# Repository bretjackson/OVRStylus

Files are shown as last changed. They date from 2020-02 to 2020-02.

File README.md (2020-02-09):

# OVR Stylus

Picture of a user holding the OVR Stylus

The OVR Stylus is an open-source software/hardware design for a 3D input stylus used in virtual and augmented reality applications. With a touch pad, two input buttons, LRA-based vibrotactile haptic feedback, and Bluetooth communication, the 3D-printed prop’s light-weight design (35g) enables creative and precise interaction.

A paper describing the implementation was published at the [Workshop on Novel Input Devices and Interaction Techniques](https://sites.google.com/view/nidit) at the IEEE Virtual Reality 2020 conference. 

This repository archives the files needed to create your own OVR Stylus or to create a modified design.

## Repository Contents

* **/Case** - 3D printing files for the stylus case (.stl, Fusion 360 .f3z)
* **/Documentation** - A copy of the NIDIT paper (.pdf)
* **/Firmware** - Arduino  code used in the stylus and central device
* **/Hardware** - Eagle design files, BOM, Gerber files (.brd, .sch, etc.)
* **/VRPN** - Patch file and stylus classes to integrate with the [VRPN library](https://github.com/vrpn/vrpn)

### Hardware Manufacture

Stylus Components

#### PCB

The hardware directory contains the design files needed to print the custom circuit board. The gerber files can be uploaded directly to manufactures (e.g. [Seeed Fusion Studio](https://www.seeedstudio.com/fusion.html)). Ordering specifications including board thickness and other properties are listed in the `PCB Specs - Ordering Info` file. The component placement list and assembly drawing can be used for pick-n-place machines if using professional assembly.

To modify the design the Autodesk Eagle design files for the schematic and board layout are also included.

#### Haptic Controller

The design uses the Fyber Labs [LRA Haptic Flex Module](https://www.tindie.com/products/fyberlabs/lra-haptic-flex-module/). A Samsung 8mm LRA motor can be purchased from the same website. Solder the motor leads to the +0 and -0 through-hole pads. Connect the PWM pad to the stylus's P3 pad. The VIN, GND, SDA, and SCL pads can be connected to the respective pads on the stylus. I recommend using 28 gauge stranded wire and making the leads very short. The haptic flex module is placed vertically at the button end of the stylus. 

#### Sliding Touch Sensor

To capture sliding touch input, a [Spectra Symbol 50mm Linear ThinPot poteniometer](https://www.amazon.com/SPECTRA-SYMBOLLINEAR-THINPOT-50-MM/dp/B005T844FU) is mounted in the groove in the top of the case. Solder leads to the potentiometer pins as described [here](https://learn.sparkfun.com/tutorials/softpot-hookup-guide/all). The 3V3 and GND leads can be kept shorter and be soldered to their respective pads on the stylus pcb near the RX and TX pads. The analog output tab's lead should be kept longer and soldered to the P4 pad at the front of the stylus (It will need to route behind the battery's JST connector). This P4 pad already contains a buildin 10kΩ resistor between the pad and ground that pulls the SoftPot's analog output signal down.

Once the soldering is complete, the potentimeter can be slide sideways into the groove in the top of the stylus case and the adhesive backing can be removed to secure it in place.

#### Battery

The case is designed to fit a [Sparkfun 110mAh Lithium ion battery](https://www.sparkfun.com/products/13853). The battery is mounted in the case underneath the PCB. The wires can either be routed to the front of the PCB and around the buttons to connect to the JST connector, or through the second large hole in the PCB.
    
### 3D Printed Case

The Case folder contains the STL files for the case. Multiple optical tracking end caps are included if multiple styluses will be made for use with the same optical tracking system.

For the prototype, the files were printed with a Makerbot Replicator 5th gen, although more professional results can be obtained with a higher quality resin printer. The prints were made with the standard settings in Makerbot Print, using support material. The top and bottom are designed to fit oriented vertically on the build platform. The support material will need to be removed with a razor blade. The button file will need to be printed twice for the two buttons.

The threading for both endcaps is ISO metric M14x2 profile. Depending on the quality of your printer, the threads may need to be cleaned up using a corresponding bolt and nut. Run the bolt a few times into the endcap to remove any extra plastic from the 3D printing.

The bottom component contains an ANSI 4-40 UNC threaded hole in the center support. This hole may also need the threads to be cleaned up using a steel bolt.

To assemble the components, mount the battery in the slot in the stylus bottom. Route the wires around the center support to the front of the stylus and the top of the board. The haptic module should sit vertically in the  space at the front. The LRA can be hot glued in the smaller slot at the front (The tabs may need to be bent slightly to clear the top of the case). The PCB can be screwed to the center support with a 1/4 inch 4-40 bolt. Place the 3D printed buttons so that they protrude from the top of the stylus, and snap the top and bottom together, making sure the buttons remain in place.  Screw on the end caps.

If the case needs to be modified, the Autodesk Fusion 360 design files are included in the Case directory.

### Software

The following section outlines the software requirements for both the stylus and the central device connected to the host computer.

#### Stylus Software

The stylus code is written for the Arduino environment. Download and install the [Arduino IDE](https://www.arduino.cc/en/Main/Software). The main stylus code is found in Firmware/Stylus.ino. To get started, open the file in the Arduino IDE.

To begin controling the LRA Haptic flex chip, you will need to install the Adafruit_DRV2605 Library. You can do that by going to the Arduino library manager under Sketch -> Include Library -> Manage Libraries... Then search for DRV2605 and find the Adafruit DRV2605 Library and click Install.

The stylus code uses the Pfod low-power Arduino Library by Mathew Ford. A tutorial for installing this software can be found [here](https://www.forward.com.au/pfod/BLE/LowPower/index.html). Below, we copy the most pertinent steps for archival purposes. 

Install [Sandeep Minstry's nRF5 library](https://github.com/sandeepmistry/arduino-nRF5):
1. Go into File → Preferences
2. Add `https://sandeepmistry.github.io/arduino-nRF5/package_nRF5_boards_index.json` as an "Additional Board Manager URL"
3. Open the Boards Manager from the Tools -> Board menu and install "Nordic Semiconductor nRF5 Boards".

Add the nRF5 Flash Softdevice tool:
1. In a terminal, cd <SKETCHBOOK>, where <SKETCHBOOK> is your Arduino Sketch folder:
OS X: ~/Documents/Arduino
Linux: ~/Arduino
Windows: ~/Documents/Arduino
2. Create the following directories: tools/nRF5FlashSoftDevice/tool/
3. Download nRF5FlashSoftDevice.jar to <SKETCHBOOK>/tools/nRF5FlashSoftDevice/tool/ (a local copy of nRF5FlashSoftDevice.jar is here)
4. Restart the Arduino IDE

Install the pfod_lp_nrf52 hardware support.
1. Download the [pfod_lp_nrf52.zip](https://www.forward.com.au/pfod/BLE/LowPower/pfod_lp_nrf52.zip) file. (A local copy can also be found in the Firmware directory.)
2. Start the Arduino IDE, Open the File → Preferences window an at the bottom find the directory where the preferences.txt file is stored. In Window's 7 you can click on that path to open the directory in the Explorer.
3. From the preferences.txt directory, open the packages sub-directory and then the sandeepmistry sub-directory which contains the hardware and tools directories.
4. Delete the hardware directory.
5. Unzip pfod_lp_nrf52.zip to the sandeepmistry directory to install the pfod low power support. This will install the modified hardware directory.
6. Close and restart the Arduino IDE.
7. Open the Tools → Board and scroll down to find the pfod low power nRF52832 boards.
8. Select the `*Redbear BLE Nano 2` board.
9. Under the Tools menu, make sure the programmer is set to `CMSIS-DAP`.

To Program the board, we use a [Particle Debugger](https://store.particle.io/products/particle-debugger). Connect the debugger's GND, SCLK, and SDIO pins to the corresponding pins at the front of the stylus PCB. If you intend to debug frequently, placing Pogo pins in a breadboard allow you to temporarly create connections with the stylus pcb easily without soldering.

Power the stylus pcb and then plug the particle debugger into a usb port on the programming computer. In the tools menu, make sure the usb is selected as the port.

Before the program can be loaded a Nordic Softdevice must be uploaded to the board. Select the `nRF52 Flash SoftDevice` option half way down the Tools menu. The project uses the S132 version 2.0.1 soft device. It is already included with the Sandeep Minstry package.

Once the flash is complete, upload the Stylus sketch onto the stylus pcb.

#### Host Central Device

Multiple BLE-supporting hardware can be used to connect with the stylus. Our implementation uses a stock [Arduino Nano 33 BLE](https://store.arduino.cc/usa/nano-33-ble) module to serve as a BLE to serial repeater. 

Load the Software:
1. Open the Boards Manager from the Tools -> Board menu and install "Arduino nRF528x Boards (Mbed OS)".
2. Select  `Arduino Nano 33 BLE` as the current board and make sure the port corresponds with the USB connection.
3. Upload the nano33_central.ino from the Firmware Directory to the Nano board.

#### VRPN

The VRPN directory contains a patch file to add the OVR Stylus files to the [VRPN library](https://github.com/vrpn/vrpn). The patch was made against commit: 3863b1e089b3070ae37e25fa4a85ab3bb138ee12

After cloning the vrpn library, apply the patch:
```
git apply vrpn_ovrstylus_changes.patch
```

The Stylus device files are also included in the VRPN directory if you would like to manually apply them.

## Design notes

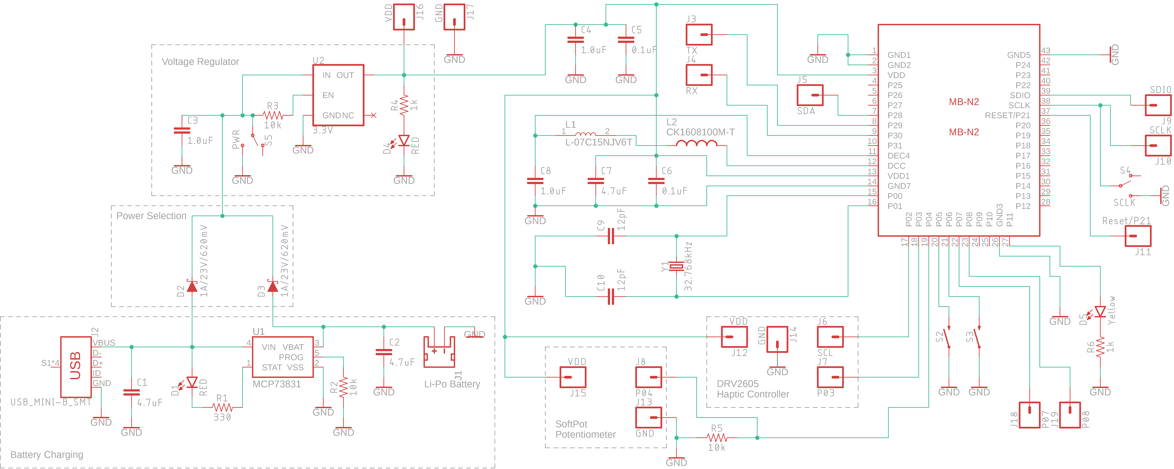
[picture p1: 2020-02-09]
Hardware/OVR-Stylus-Schematic.png

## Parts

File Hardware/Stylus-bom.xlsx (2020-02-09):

Ref Des | MP | Quantity | DIGI-KEY_PURCHASE_URL | MF | DIGI-KEY_PART_NUMBER | Description
C1, C2, C7 | CL10A475MQ8NNNC | 3 | https://www.digikey.com/product-detail/en/samsung-electro-mechanics/CL10A475MQ8NNNC/1276-1907-1-ND/3889993 | Samsung | 1276-1907-1-ND | 4.7 µF ceramic capacitor 20% 6.3V X5R 0603
C3, C4, C8 | CL10A105KO8NNNC | 3 | https://www.digikey.com/product-detail/en/samsung-electro-mechanics/CL10A105KO8NNNC/1276-1034-1-ND/3889120 | Samsung | 1276-1034-1-ND | 1µF ±10% 16V Ceramic Capacitor X5R 0603
C5, C6 | CL10B104KB8NNNL | 2 | https://www.digikey.com/product-detail/en/samsung-electro-mechanics/CL10B104KB8NNNL/1276-CL10B104KB8NNNLCT-ND/10320686 | Samsung | 1276-CL10B104KB8NNNLCT-ND | 0.1µF ±10% 50V Ceramic Capacitor X7R 0603
C9, C10 | CL10C120JB8NNNC | 2 | https://www.digikey.com/product-detail/en/samsung-electro-mechanics/CL10C120JB8NNNC/1276-1254-1-ND/3889340 | Samsung | 1276-1254-1-ND | 12pF ±5% 50V Ceramic Capacitor C0G, NP0 0603
D1 | LTST-C150KRKT | 1 | https://www.digikey.com/product-detail/en/lite-on-inc/LTST-C150KRKT/160-1405-1-ND/386760 | Lite-On Inc. | 160-1405-1-ND | LED RED CLEAR 1206 SMD
D2, D3 | BAT20JFILM | 2 | https://www.digikey.com/product-detail/en/BAT20JFILM/497-3381-1-ND/669138/?itemSeq=300405593 | STMicroelectronics | 497-3381-1-ND | Diode Schottky 23V 1A Surface Mount SOD-323
D4 | 5988010107F | 1 | https://www.digikey.com/product-detail/en/dialight/5988010107F/350-2029-1-ND/1291333 | Dialight | 350-2029-1-ND | LED RED CLEAR 0603 SMD
D5 | LTST-C150KSKT | 1 | https://www.digikey.com/product-detail/en/lite-on-inc/LTST-C150KSKT/160-1406-1-ND/386762 | Lite-On Inc. | 160-1406-1-ND | LED YELLOW CLEAR 1206 SMD
J1 | S2B-PH-SM4-TB(LF)(SN) | 1 | https://www.digikey.com/product-detail/en/jst-sales-america-inc/S2B-PH-SM4-TB-LF-SN/455-1749-1-ND/926846 | JST Sales America Inc. | 455-1749-1-ND | JST CONN HEADER SMD R/A 2POS 2MM
J2 | MUSB-05-F-B-SM-A-K-TR | 1 | https://www.digikey.com/product-detail/en/samtec-inc/MUSB-05-F-B-SM-A-K-TR/SAM13208CT-ND/8827963 | Samtec Inc. | SAM13208CT-ND | USB type Mini-B Connector
L1 | L-07C15NJV6T | 1 | https://www.digikey.com/product-detail/en/johanson-technology-inc/L-07C15NJV6T/712-1408-1-ND/1840086 | Johanson Technology | 712-1408-1-ND | Inductor RF Chip Multi-Layer 15nH 5% 100MHz 8Q-Factor Ceramic 250mA 600mOhm DCR 0402 T/R
L2 | CK1608100M-T | 1 | https://www.digikey.com/product-detail/en/taiyo-yuden/CK1608100M-T/587-1684-1-ND/1007998 | Taiyo Yuden | 587-1684-1-ND | INDUCTOR, 10UH, 50mA, 20%, 17MHZ, SMD
R1 | ERA-3AEB331V | 1 | https://www.digikey.com/product-detail/en/panasonic-electronic-components/ERA-3AEB331V/P330DBCT-ND/1466040 | Panasonic | P330DBCT-ND | 330 Ohms ±0.1% 0.1W, 1/10W Chip Resistor 0603
R2, R3, R5 | RR0816P-103-D | 3 | https://www.digikey.com/product-detail/en/susumu/RR0816P-103-D/RR08P10.0KDCT-ND/432748 | Susumu | RR08P10.0KDCT-ND | 10 kOhms ±0.5% 0.063W, 1/16W Chip Resistor 0603
R4, R6 | RR0816P-102-D | 2 | https://www.digikey.com/product-detail/en/susumu/RR0816P-102-D/RR08P1.0KDCT-ND/432724 | Susumu | RR08P1.0KDCT-ND | 1 kOhms ±0.5% 0.063W, 1/16W Chip Resistor 0603
S2, S3 | TL3315NF160Q | 2 | https://www.digikey.com/product-detail/en/e-switch/TL3315NF160Q/EG4621CT-ND/1870401 | E-Switch | EG4621CT-ND | Momentary Switch (Pushbutton) - SPST 4.5mm
S4 | AYZ0202AGRLC | 1 | https://www.digikey.com/product-detail/en/c-k/AYZ0202AGRLC/401-2013-1-ND/1640122 | C&K | 401-2013-1-ND | Double Pole, Double Throw (DPDT) Switch
S5 | MA12RTR | 1 | https://www.digikey.com/product-detail/en/apem-inc/MA12RTR/679-1847-1-ND/1973774 | APEM Inc. | 679-1847-1-ND | SWITCH SLIDE SPDT 300MA 4V Right Angle
MB-N2 | MB-N2 | 1 | CUSTOMER SUPPLIED | RedBearLab/Particle | CUSTOMER SUPPLIED | Redbearlab MB-N2 ble microcontroller
U1 | MCP73831T-2ATI/OT | 1 | https://www.digikey.com/product-detail/en/microchip-technology/MCP73831T-2ATI-OT/MCP73831T-2ATI-OTCT-ND/1979803 | Microchip Technology | MCP73831T-2ATI/OTCT-ND | MCP73831T Li-Ion, Li-Pol Controller
U2 | AP2112K-3.3TRG1 | 1 | https://www.digikey.com/product-detail/en/diodes-incorporated/AP2112K-3.3TRG1/AP2112K-3.3TRG1DICT-ND/4505257 | Diodes Incorporated | AP2112K-3.3TRG1DICT-ND | AP2112 - 600mA CMOS LDO Regulator w/ Enable
Y1 | SC32S-12.5PF20PPM | 1 | https://www.digikey.com/product-detail/en/seiko-instruments/SC32S-12.5PF20PPM/728-1073-1-ND/4931507 | Seiko Instruments | 728-1073-1-ND | 32.768kHz ±20ppm Crystal 12.5pF 70 kOhms 2-SMD, No Lead

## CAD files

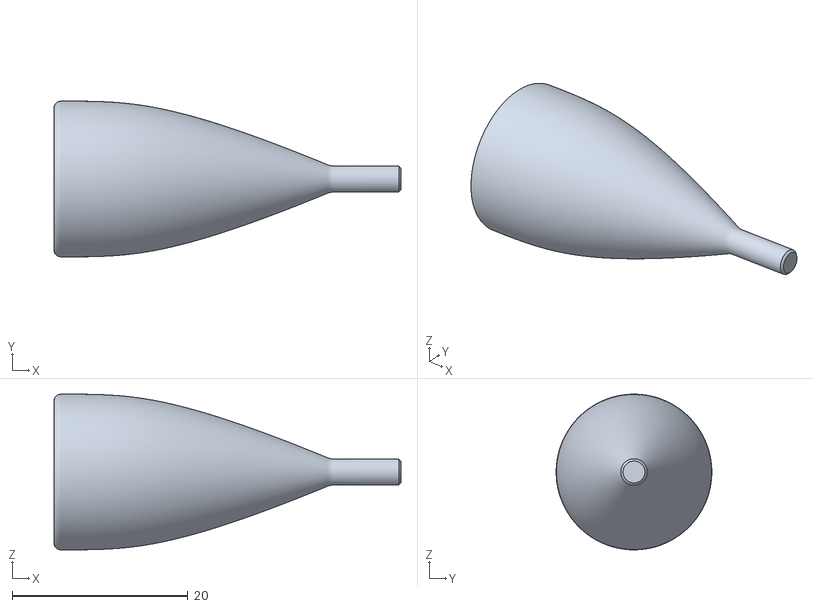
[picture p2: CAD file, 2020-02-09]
Case/tip.stl
39.5 x 17.7 x 17.7

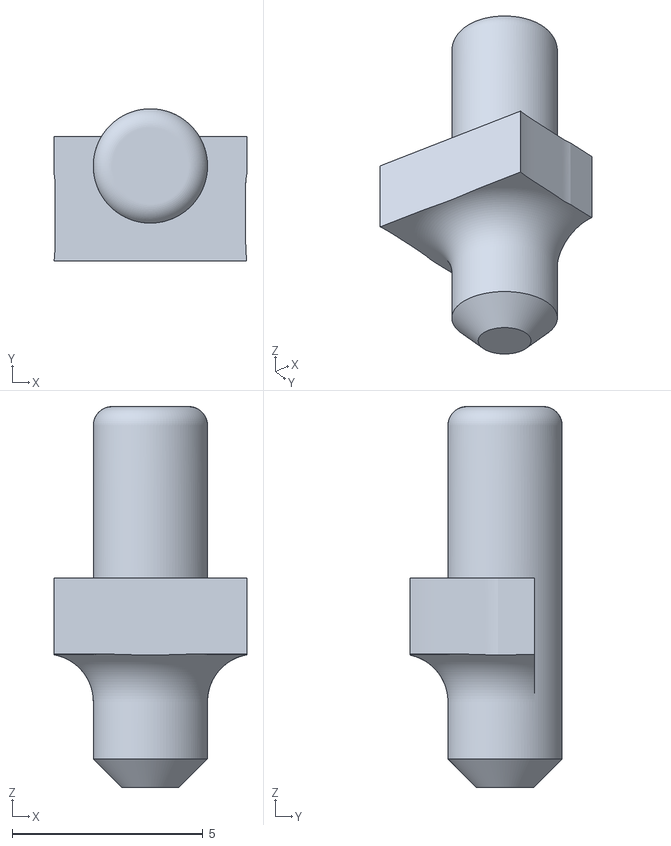
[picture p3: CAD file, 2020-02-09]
Case/button.stl
5.06 x 4.00 x 10.0

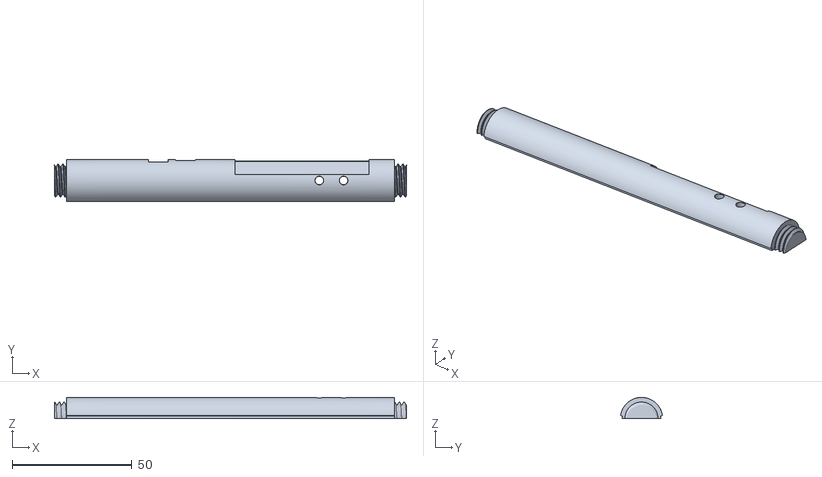
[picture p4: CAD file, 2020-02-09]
Case/top.stl
147.0 x 17.5 x 8.85

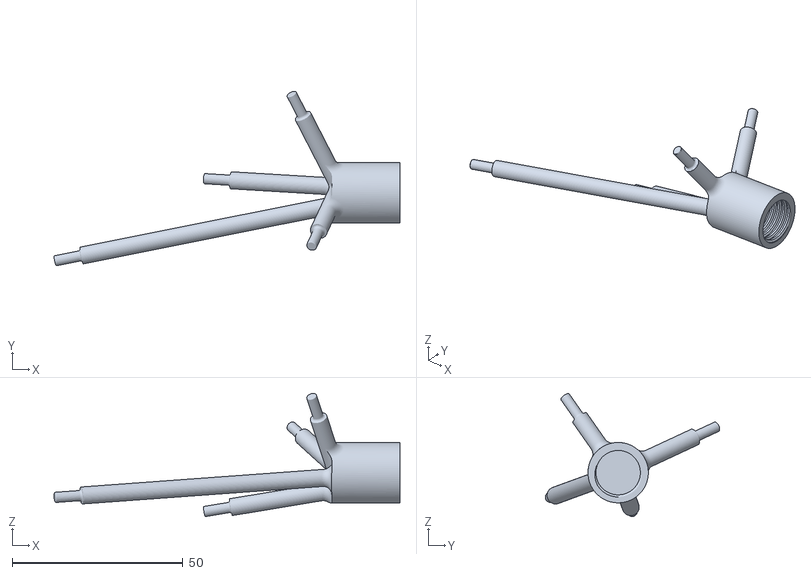
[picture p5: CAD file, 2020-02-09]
Case/cap2.stl
101.5 x 51.2 x 36.1

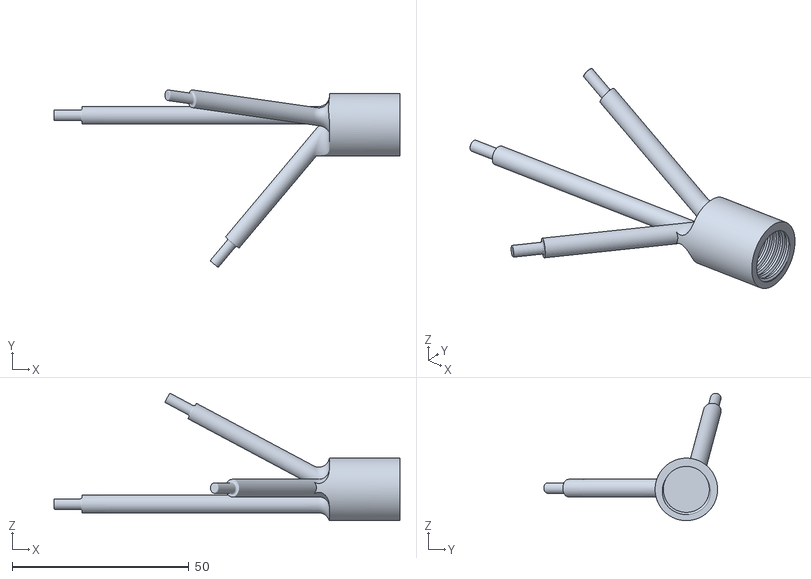
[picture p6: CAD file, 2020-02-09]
Case/cap1.stl
98.0 x 50.2 x 36.0

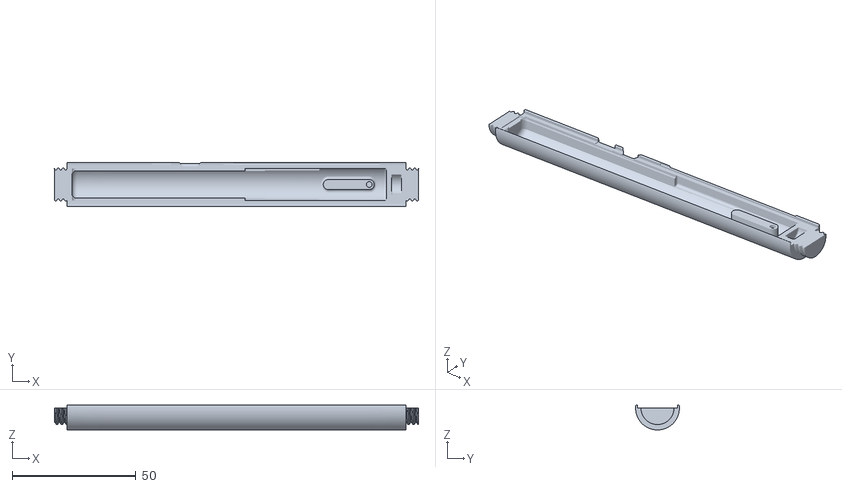
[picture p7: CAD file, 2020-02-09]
Case/bottom.stl
147.0 x 17.7 x 10.1

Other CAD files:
Case/stylus-fusion360.f3z

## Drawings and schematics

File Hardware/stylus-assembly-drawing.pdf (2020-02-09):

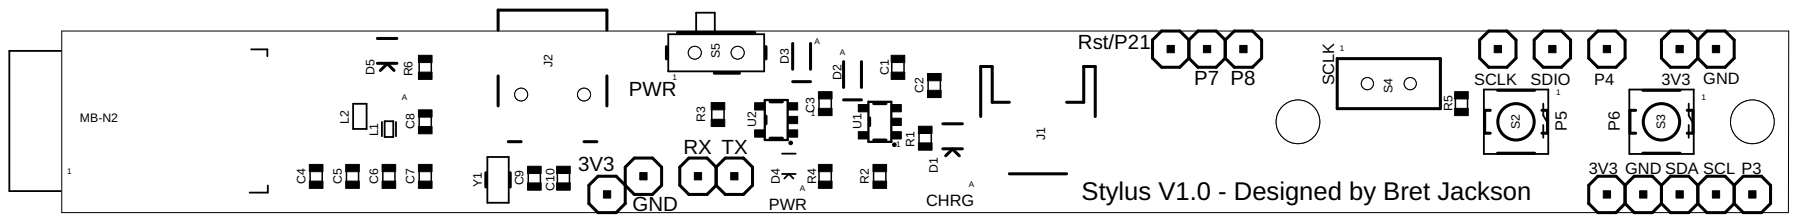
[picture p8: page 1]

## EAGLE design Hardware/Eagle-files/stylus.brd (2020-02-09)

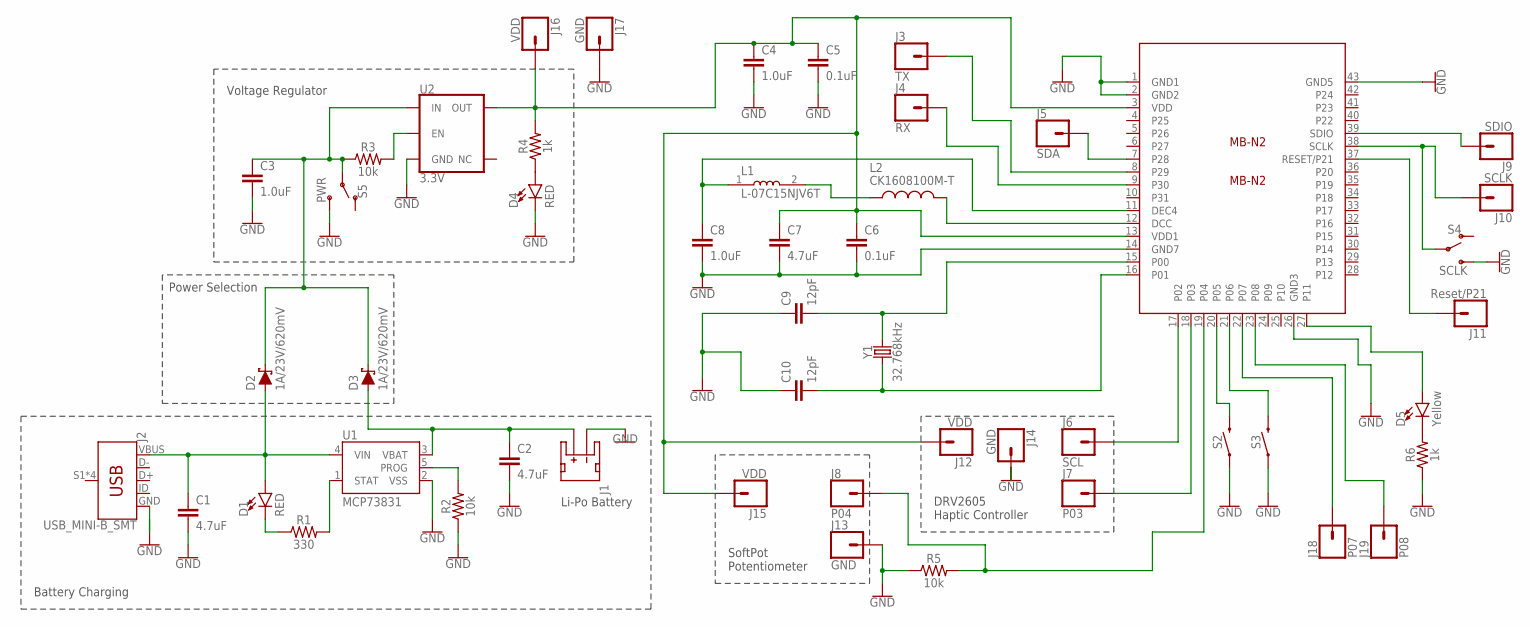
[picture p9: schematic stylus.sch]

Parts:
C1, C2, C7: 4.7uF; 0603
C3, C4, C8: 1.0uF; 0603
C5, C6: 0.1uF; 0603
C9, C10: 12pF; 0603
D1: RED; LED-1206
D2, D3: 1A/23V/620mV; SOD-323
D4: RED; LED-0603
D5: Yellow; LED-1206
J1: LIPO Bat; JST-2-SMD
J2: USB_MINI-B_SMT; USB-MINIB
J3: TX; 1X01
J4: RX; 1X01
J5: SDA; 1X01
J6: SCL; 1X01
J7: P03; 1X01
J8: P04; 1X01
J9: SDIO; 1X01
J10: SCLK; 1X01
J11: Reset/P21; 1X01
J12, J15, J16: VDD; 1X01
J13, J14, J17: GND; 1X01
J18: P07; 1X01
J19: P08; 1X01
L1: L-07C15NJV6T; INDC1005X60N
L2: CK1608100M-T; INDC1608X95N
MB-N2: MB-N2
R1: 330; 0603
R2, R3, R5: 10k; 0603
R4, R6: 1k; 0603
S2, S3: MOMENTARY-SWITCH-SPST-SMD-4.5MM; TACTILE_SWITCH_SMD_4.5MM
S4: SCLK; SWITCH_DPDT_SMD_AYZ0202
S5: PWR; SWITCH_SPST_SMD_A
U1: MCP73831; SOT23-5
U2: 3.3V; SOT23-5
Y1: 32.768kHz; CRYSTAL-SMD-3.2X1.5MM

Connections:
DCC: L2.2, MB-N2.12 (DCC)
DEC4: C8.1, L1.1, MB-N2.11 (DEC4)
EN: R3.2, U2.3 (EN)
GND: C1.2, C2.2, C3.2, C4.2, C5.2, C6.2, C7.2, C8.2, C9.1, C10.1, D4.C, J1.1 (-), J2.GND, J13.1, J14.1, J17.1, MB-N2.1 (GND1), MB-N2.2 (GND2), MB-N2.14 (GND7), MB-N2.26 (GND3), MB-N2.43 (GND5), R2.1, R5.1, R6.1, S2.2 (1), S2.3 (1), S3.2 (1), S3.3 (1), S4.3 (S), S5.3 (S), U1.2 (VSS), U2.2 (GND)
unnamed: D1.C, R1.1
unnamed: D4.A, R4.1
unnamed: L1.2, L2.1
unnamed: C9.2, MB-N2.15 (P00), Y1.P$2 (2)
unnamed: C10.2, MB-N2.16 (P01), Y1.P$1 (1)
unnamed: J11.1, MB-N2.37 (RESET/P21)
unnamed: D5.A, MB-N2.27 (P11)
unnamed: D5.C, R6.2
P03: J7.1, MB-N2.18 (P03)
P04: J8.1, MB-N2.19 (P04), R5.2
P05: MB-N2.20 (P05), S2.1 (2), S2.4 (2)
P06: MB-N2.21 (P06), S3.1 (2), S3.4 (2)
P07: J18.1, MB-N2.22 (P07)
P08: J19.1, MB-N2.23 (P08)
PROG: R2.2, U1.5 (PROG)
RX: J4.1, MB-N2.9 (P30)
SCL: J6.1, MB-N2.17 (P02)
SCLK: J10.1, MB-N2.38 (SCLK), S4.2
SDA: J5.1, MB-N2.7 (P28)
SDIO: J9.1, MB-N2.39 (SDIO)
STAT: R1.2, U1.1 (STAT)
TX: J3.1, MB-N2.8 (P29)
VBAT: C2.1, D3.A, J1.2 (+), U1.3 (VBAT)
VDD: C4.1, C5.1, C6.1, C7.1, J12.1, J15.1, J16.1, MB-N2.3 (VDD), MB-N2.13 (VDD1), R4.2, U2.5 (OUT)
VIN: C1.1, D1.A, D2.A, J2.VBUS, U1.4 (VIN)
VR-IN: C3.1, D2.C, D3.C, R3.1, S5.2, U2.1 (IN)

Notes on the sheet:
Power Selection
DRV2605 Haptic Controller
SoftPot Potentiometer
Li-Po Battery
Voltage Regulator
Battery Charging

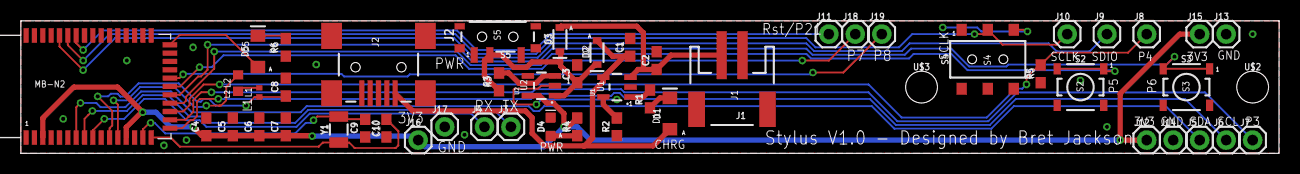
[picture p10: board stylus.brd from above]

Board: 2 copper layers, 120.7 x 12.7 mm, 52 parts (0 on the bottom side), 30 nets.

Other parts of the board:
U$2, U$3: STAND-OFF-TIGHT

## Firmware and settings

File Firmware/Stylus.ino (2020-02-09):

/* ================================================================================
 * This file is part of the OVR Stylus Open Source Project, which is developed and 
 * maintained by Bret Jackson, Macalester College.
 *
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
 * THE SOFTWARE IS PROVIDED “AS IS”, WITHOUT WARRANTY OF ANY KIND, EXPRESS OR IMPLIED, INCLUDING BUT NOT 
 * LIMITED TO THE WARRANTIES OF MERCHANTABILITY, FITNESS FOR A PARTICULAR PURPOSE AND NONINFRINGEMENT. IN 
 * NO EVENT SHALL THE AUTHORS OR COPYRIGHT HOLDERS BE LIABLE FOR ANY CLAIM, DAMAGES OR OTHER LIABILITY, 
 * WHETHER IN AN ACTION OF CONTRACT, TORT OR OTHERWISE, ARISING FROM, OUT OF OR IN CONNECTION WITH THE 
 * SOFTWARE OR THE USE OR OTHER DEALINGS IN THE SOFTWARE.
 */
 
#include <lp_BLESerial.h>

#include <Wire.h>
#include "Adafruit_DRV2605.h"

Adafruit_DRV2605 drv;


int led = 13;
int buttonPin0 = 4;
int buttonPin1 = 7;
int softpotPin = 5;

int button0State = 1;
int button1State = 1;
int softpotState = 0;
boolean stateChanged = false;

int previousSoftPotADC = 0;

lp_BLESerial ble;

lp_timer sleepTimer;
const unsigned long DELAY_TIME = 2; // mS

const byte MESSAGE_DELIMITER = '!';
char endMarker = '\n';
char rc;
const byte numChars = 32;
char receivedChars[numChars];
int hapticEffectId = 0; 
boolean newData = false;


void setup() {

  pinMode(buttonPin0, INPUT_PULLUP); // pin is LOW when pressed
  pinMode(buttonPin1, INPUT_PULLUP);
  pinMode(softpotPin, INPUT);
  pinMode(led, OUTPUT);

  drv.begin();
  drv.selectLibrary(1);
  // I2C trigger by sending 'go' command
  // default, internal trigger when sending GO command
  drv.setMode(DRV2605_MODE_INTTRIG);

  // initialize the digital pin as an output.
  ble.setName("OVR Stylus"); // Advertised name
  ble.setConnectedHandler(handleConnection);
  ble.setDisconnectedHandler(handleDisconnection);
  ble.setConnectionInterval(1,1);
  ble.setAdvertisingInterval(20);
  ble.begin(); // start advertising and be ready to accept connections
}

void loop() {
  sleep(); // just sleep here waiting a trigger

  static byte ndx = 0;
  while (ble.available() > 0) {
    rc = ble.read();

    if (rc != endMarker) {
      receivedChars[ndx] = rc;
      ndx++;
      if (ndx >= numChars) {
        ndx = numChars - 1;
      }
    }
    else {
      receivedChars[ndx] = '\0'; // terminate the string
      ndx = 0;
      newData = true;
    }
    
    if (newData == true) {
        hapticEffectId = 0;
        hapticEffectId = atoi(receivedChars);
        if (hapticEffectId > 0 && hapticEffectId < 124) {
          playHapticEffect(hapticEffectId);
        }
        newData = false;
    }
  }
}

void playHapticEffect(int effectId) {
  // set the effect to play
  drv.setWaveform(0, effectId);  // play effect
  drv.setWaveform(1, 0);       // end waveform

  // play the effect!
  drv.go();
}

void handleSleepTimer() {
  int button0 = digitalRead(buttonPin0);
  int button1 = digitalRead(buttonPin1);
  
  int softPotADC = analogRead(softpotPin);
  float alpha = 0.2;
  int EWMF = (1.0-alpha)*previousSoftPotADC + alpha*softPotADC; // exponential smoothing filter
  previousSoftPotADC = EWMF;
  int softPotPosition = map(EWMF, 0, 1023, 0, 63);
  
  if (button0 != button0State) {
    button0State = button0;
    stateChanged = true;
  }
  if (button1 != button1State) {
    button1State = button1;
    stateChanged = true;
  }
  if (softPotPosition != softpotState) {
    softpotState = softPotPosition;
    stateChanged = true;
  }

  if (stateChanged) {
    sendStateUpdate();
  }
  sleepTimer.start(DELAY_TIME, handleSleepTimer, APP_TIMER_MODE_SINGLE_SHOT);
}

void handleButton0PinLevelChange() {
  button0State = !button0State;
  stateChanged = true;
}

void handleButton1PinLevelChange() {
  button1State = !button1State;
  stateChanged = true;
}

void sendStateUpdate() {
  stateChanged = false;
  if (button0State == 0 || button1State == 0) {
    digitalWrite(led, HIGH);
  }
  else {
    digitalWrite(led, LOW);
  }

  //Message Format:
  //    '!' as delimiter byte
  //    second byte contains states:
  //        - Leftmost bit for button0,
  //        - Second highest bit is button1,
  //        - 6 rightmost bits to represent softpot value (converting 0-1023 to 0-63)
    byte states = 0b00000000;
    if (button0State == LOW) {
      bitSet(states, 7);
    }
    if (button1State == LOW) {
      bitSet(states, 6);
    }
 
    for(int i = 0; i < 6; i++) {
      if (bitRead(softpotState, i)) {
        bitSet(states, i);
      }
    }

  //ble.write(MESSAGE_DELIMITER); ble.print(button0State); ble.print(button1State); ble.println(softpotState);//ble.write(states);
  ble.write(MESSAGE_DELIMITER); ble.write(states);
  ble.flush();
}

void handleConnection(BLECentral& central) {
  sleepTimer.start(DELAY_TIME, handleSleepTimer, APP_TIMER_MODE_SINGLE_SHOT);
}

void handleDisconnection(BLECentral& central) {
  sleepTimer.stop();
}

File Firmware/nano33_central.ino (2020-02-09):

/* ================================================================================
 * This file is part of the OVR Stylus Open Source Project, which is developed and 
 * maintained by Bret Jackson, Macalester College.
 *
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
 * THE SOFTWARE IS PROVIDED “AS IS”, WITHOUT WARRANTY OF ANY KIND, EXPRESS OR IMPLIED, INCLUDING BUT NOT 
 * LIMITED TO THE WARRANTIES OF MERCHANTABILITY, FITNESS FOR A PARTICULAR PURPOSE AND NONINFRINGEMENT. IN 
 * NO EVENT SHALL THE AUTHORS OR COPYRIGHT HOLDERS BE LIABLE FOR ANY CLAIM, DAMAGES OR OTHER LIABILITY, 
 * WHETHER IN AN ACTION OF CONTRACT, TORT OR OTHERWISE, ARISING FROM, OUT OF OR IN CONNECTION WITH THE 
 * SOFTWARE OR THE USE OR OTHER DEALINGS IN THE SOFTWARE.
 */

//#define DEBUG

#include <ArduinoBLE.h>

const int ledPin =  LED_BUILTIN;// the number of the LED pin
int ledState = LOW;             // ledState used to set the LED
unsigned long previousMillis = 0;        // will store last time LED was updated
const long interval = 500;

void setup() {
  Serial.begin(115200);
  while (!Serial);

  // Set the timeout on input-string parsing to 1ms, so we
  // don't waste a lot of time waiting for the completion of
  // numbers.
  Serial.setTimeout(1);

  pinMode(ledPin, OUTPUT);

  // initialize the BLE hardware
  BLE.begin();

#ifdef DEBUG
  Serial.println("BLE Central - OVR Stylus");
  Serial.println("Scanning for Nordic UART peripherals named 'OVR Stylus'...");
#endif

  // start scanning for peripherals
  BLE.scanForUuid("6e400001-b5a3-f393-e0a9-e50e24dcca9e");
}

void loop() {
  // check if a peripheral has been discovered
  BLEDevice peripheral = BLE.available();

  if (peripheral) {
    ledState = LOW;
    digitalWrite(ledPin, ledState);
    
#ifdef DEBUG
    // discovered a peripheral, print out address, local name, and advertised service
    Serial.print("Found ");
    Serial.print(peripheral.address());
    Serial.print(" '");
    Serial.print(peripheral.localName());
    Serial.print("' ");
    Serial.print(peripheral.advertisedServiceUuid());
    Serial.println();
#endif

    if (peripheral.localName() == "OVR Stylus") {
      // stop scanning
      BLE.stopScan();

      repeatBLEToSerial(peripheral);

      // peripheral disconnected, start scanning again
#ifdef DEBUG
      Serial.println("Scanning for Nordic UART peripherals named 'OVR Stylus'...");
#endif
      BLE.scanForUuid("6e400001-b5a3-f393-e0a9-e50e24dcca9e");
    }
  }
  else {
    // Serial.println("Waiting for available peripheral");
    unsigned long currentMillis = millis();

    if (currentMillis - previousMillis >= interval) {
      // save the last time you blinked the LED
      previousMillis = currentMillis;

      // if the LED is off turn it on and vice-versa:
      if (ledState == LOW) {
        ledState = HIGH;
      } else {
        ledState = LOW;
      }

      // set the LED with the ledState of the variable:
      digitalWrite(ledPin, ledState);
    }
  }
}

void repeatBLEToSerial(BLEDevice peripheral) {
  // connect to the peripheral
#ifdef DEBUG
  Serial.print("Connecting ...   ");
#endif

  if (peripheral.connect()) {
#ifdef DEBUG
    Serial.println("Connected");
#endif
  } else {
#ifdef DEBUG
    Serial.println("Failed to connect");
#endif
    return;
  }

  // discover peripheral attributes
#ifdef DEBUG
  Serial.print("Discovering attributes ...   ");
#endif
  if (peripheral.discoverAttributes()) {
#ifdef DEBUG
    Serial.println("Attributes discovered");
#endif
  } else {
#ifdef DEBUG
    Serial.println("Attribute discovery failed");
#endif
    peripheral.disconnect();
    return;
  }

  // retrieve the characteristics
  BLECharacteristic rxCharacteristic = peripheral.characteristic("6e400002-b5a3-f393-e0a9-e50e24dcca9e");
  BLECharacteristic txCharacteristic = peripheral.characteristic("6e400003-b5a3-f393-e0a9-e50e24dcca9e");

  if (!rxCharacteristic) {
#ifdef DEBUG
    Serial.println("Peripheral does not have RX characteristic");
#endif
    peripheral.disconnect();
    return;
  } else if (!rxCharacteristic.canWrite()) {
#ifdef DEBUG
    Serial.println("Peripheral does not have a writable RX characteristic");
#endif
    peripheral.disconnect();
    return;
  } else {
#ifdef DEBUG
    Serial.println("Can write to RX characteristic");
#endif
  }

  if (!txCharacteristic) {
#ifdef DEBUG
    Serial.println("Peripheral does not have TX characteristic");
#endif
    peripheral.disconnect();
    return;
  } else if (!txCharacteristic.canSubscribe()) {
#ifdef DEBUG
    Serial.println("TX characteristic is not subscribable");
#endif
    peripheral.disconnect();
    return;
  } else if (!txCharacteristic.subscribe()) {
#ifdef DEBUG
    Serial.println("Subscription to TX characteristic failed");
#endif
    peripheral.disconnect();
    return;
  } else {
#ifdef DEBUG
    Serial.println("Subscribed to TX Characterisitic");
#endif
  }

  while (peripheral.connected()) {
    // while the peripheral is connected

    if (Serial.available() > 0) {
      // get incoming byte:
      byte inByte = Serial.read();
#ifdef DEBUG
      Serial.print("Writing: ");
      Serial.write(inByte);
      Serial.println(" ");
#endif

      rxCharacteristic.writeValue(inByte);
    }

    if (txCharacteristic.valueUpdated()) {
      byte outBytes[20]; // lp_BLESerial.h buffers in sets of 20 bytes
      int readLen = txCharacteristic.readValue(outBytes, 20);
      Serial.write(outBytes, readLen);
    }
  }

#ifdef DEBUG
  Serial.println("Peripheral disconnected");
#endif
}

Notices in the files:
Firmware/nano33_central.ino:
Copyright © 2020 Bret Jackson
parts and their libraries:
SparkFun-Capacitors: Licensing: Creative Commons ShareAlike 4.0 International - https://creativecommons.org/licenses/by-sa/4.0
